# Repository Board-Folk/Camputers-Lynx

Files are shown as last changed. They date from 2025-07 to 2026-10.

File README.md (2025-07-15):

# Camputers Lynx 48/96/128/192

Repository for the 2023 Board Folk Recreation of the main boards of the Camputers Lynx 48/96K and 128K (192K) computers.

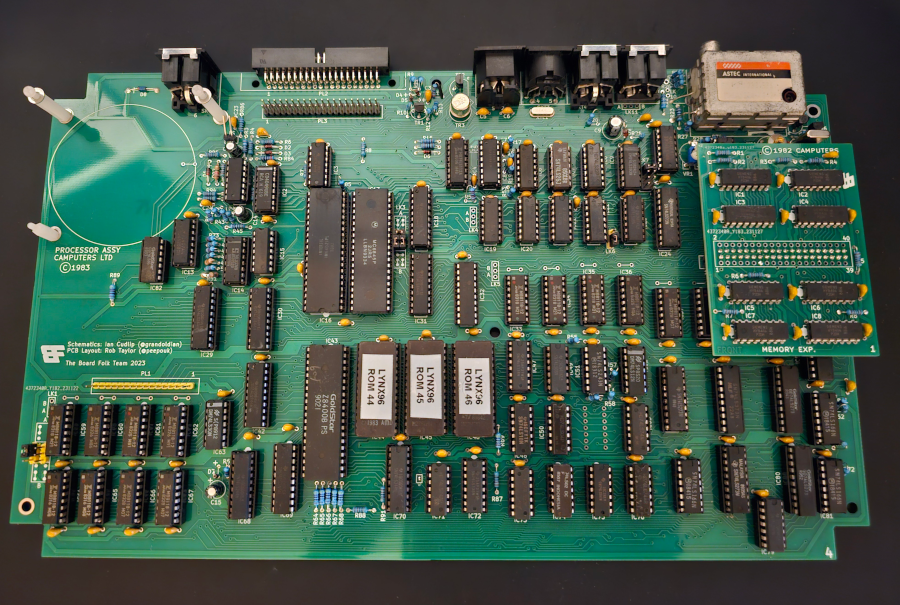
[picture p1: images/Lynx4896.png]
Built 48/96K board in Green


** Work in progress **

The original 48/96K system can be found in the Lynx 96 folder. The system needs the 16K RAM expansion board to operate (see Expansions folder). This was originally supplied as a 48K system (16K+16K+16K) then retrofitted after market by the manufacturer to be a 96K system (64K+16K+16K). It's the same board.

The second system that started production, the 128, is in the Lynx 128 folder. This system in production had presets to 128K, though could have 192K fitted. The 128K preset board (untested) can be found here. There's also a tested board without presets which can be jumpered to use 192K and can be found in the archive subfolder off here. 

Though the board without presets and appropriate jumpers set has been tested, and seems to work fine, any attempts for it to use 192K failed. It's perceived that it might need a different set of ROMs that we don't have. We're not experts and will have to defer to the Lynx community on that. See the info folder in there for jumper settings.

Be wary, the two systems aren't 100% compatible. The most compatible system is a Lynx 48 for games. The Lynx 128, compatibility was much reduced, though CP/M (untested) was an option with ROM replacements and a disc interface.

Kicad files, Gerbers and iBOMs in their respective folders for now. More information, pictures, etc may follow in time.

Keyboard boards can be found off the Expansions sub-folder in Lynx 96.

To note, we had terrible problems with RCA brand CD4538BE building these, please avoid.

## Credit

PCB layouts by Rob Taylor @peepouk. Schematics recreated by Ian Cudlip @grandoldian.

## Thanks

  * The rest of the Board Folk Team

## Legal

As the product of this project is a replica of a proprietary product, the the author makes no claim of copyright to the schematics nor PCB layouts and releases these into the public domain, solely for the purposes of study and historical preservation.

You are free to produce PCBs based on this project's designs at your own risk and without limitation, for your own use or for sale and/or repair at a reasonable price. Attribution is appreciated. The authors are not obliged to provide support of any kind. 

Under no circumstances will the authors be held responsible or liable in any way for losses, damages or costs resulting from the use of the information and/or resources of this project. 

The resources are provided "as-is" without warranty of any kind, either expressed or implied, including, but not limited to, the implied warranties of merchantability and fitness for a particular purpose.

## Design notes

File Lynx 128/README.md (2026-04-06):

# Camputers Lynx 128K

 Camputers Lynx 128K Mark 2 Issue A

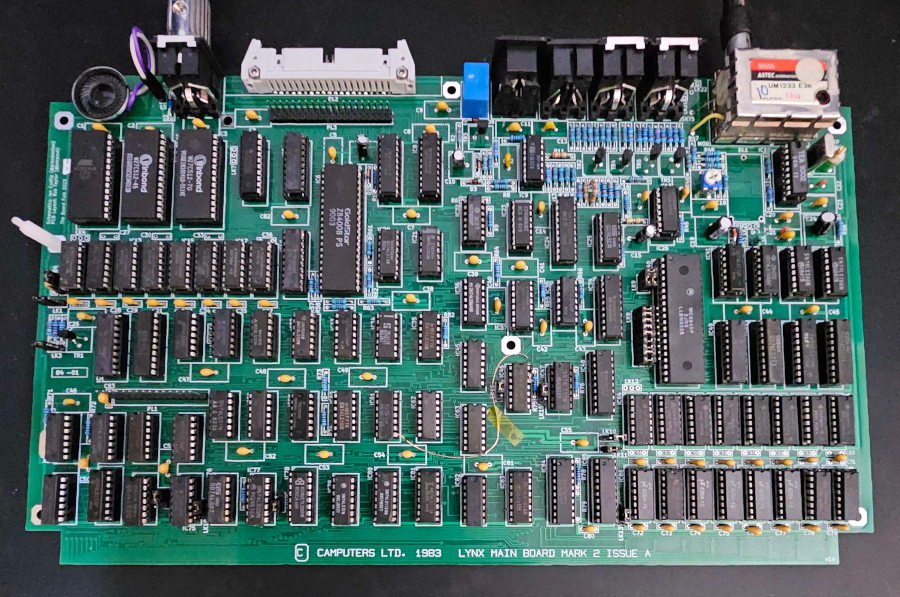
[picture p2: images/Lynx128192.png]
Built 192K board in green


The version in this folder hasn't been made. We don't see why this shouldn't work. We have tested the board in the Archive/Lynx 192 folder though, but not working to 192K capacity, see any notes in there. That version does not have the RAM configuration jumpers preset which we perceive might be beneficial to some. This still needs the single bodge wire running, will try to dig out the exact details, it's been a while. Other factory bodges (to the bottom) were to fix factory defects that aren't present on this board.

Alternatives for the relay are the Fujitsu 211A 0005-M, and the JRC-21F(4100) 5V (found on AliExpress). The OUAZ-SH-105D is *not* pin compatible. It's the same relay as found on the Acorn Electron and BBC Micro.

This is a horrible merry-go-round of a board to debug and not for the feint hearted.

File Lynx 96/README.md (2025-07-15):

# Camputers-Lynx-96K

Camputers Lynx 48/96K Issue 4

Built 48/96K board in Green

For jumper settings, see the info folder.

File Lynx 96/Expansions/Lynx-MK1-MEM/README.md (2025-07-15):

# Lynx MK1 MEM (Improved)

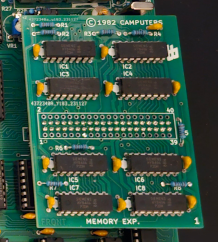
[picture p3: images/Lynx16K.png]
Built 16K expansion board in green


Lynx MK1 16K Memory Expansion

This is a replica, with modifications moving a capacitor and adding holes for straight pin socket headers.

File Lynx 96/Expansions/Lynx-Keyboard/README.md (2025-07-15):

# Lynx Keyboard

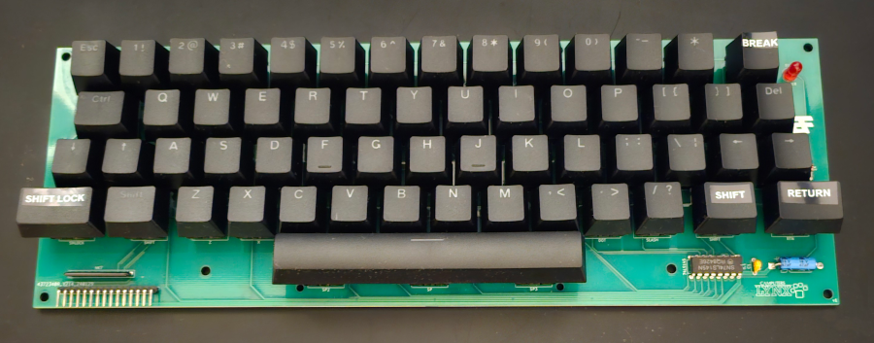
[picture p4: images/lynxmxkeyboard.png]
Built MX compatible keyboard board in green with black keycaps


Lynx MX Keyswitch Compatible Keyboard

Thanks to Graham Thornton for measurements. We've still not been able to try see if it fits an original case though.

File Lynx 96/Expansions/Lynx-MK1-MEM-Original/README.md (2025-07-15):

# Lynx MK1 MEM (Original)

Lynx MK1 16K Memory Expansion

This is an replica, please note the offset on the pin sockets. The main folder contains an updated version with straight pins.

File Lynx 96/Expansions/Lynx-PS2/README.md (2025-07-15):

# Lynx PS2

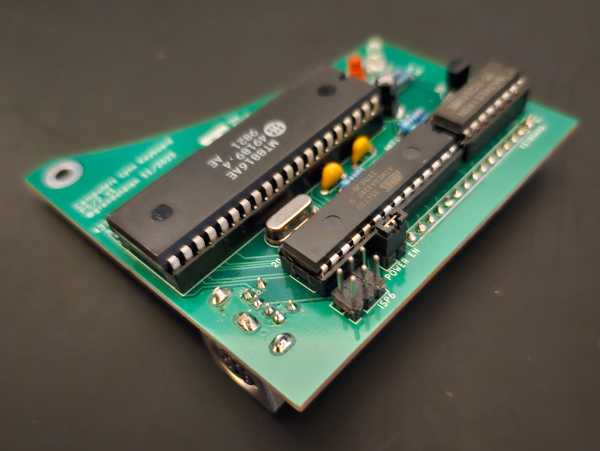
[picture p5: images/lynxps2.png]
Built PS/2 interface board in Green


ATMega328 based PS/2 Keyboard Adapter for the Camputers Lynx. Arduino code and exported binaries in the Arduino folder.

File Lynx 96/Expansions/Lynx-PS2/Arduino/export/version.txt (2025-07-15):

# Lynx PS/2 Keyboard / atmega328p
# Ian Cudlip @grandoldian 12/2023

v0

Initial version
Print Screen as NMI reset "Break"

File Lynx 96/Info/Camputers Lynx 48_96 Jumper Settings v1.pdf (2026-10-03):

LK1

# Camputers Lynx 48/96K Mark I Jumper Settings @grandoldian 10/2026 v1.2 (Board Folk v1n Board)

1

3

2

B

A

System RAM Bank 1 Pin 1
Voltage Selection
4116 RAM
1-2 -5V

3

2

1

4164/8118
RAM
NF

LK3

B

Video RAM (Bank 2)
Mode Selection

1

3

2

4

6

5

Default
1-4
2-3
5-6

LK2
A

B

System RAM Bank 1 Pin 8 and 9 Mode Selection

1

3

2

4

6

5

4164 RAM
1-2 5V
4-5 A7

1

3

2

4

6

5

4116 RAM
2-3 12V
5-6 5V

1

3

2

4

6

5

8118 RAM
1-2 5V
4-6 NF

1

3

2

4

6

5

Extended
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
VCLK Selection
(Not Fitted / Preconfigured) 12MHz
(Default)

1

2

3

24Mhz

LK5

3

1

2

B

A

Video RAM Bank 2 Pin 9
Mode Selection
4116 RAM
2-3 +5V

1

2

3

4164
RAM
1-2 A7

LK6

3

1

2

B

A

/VCASII Select
Use 1-2 (South)
Unknown
(?)

1

2

3

Default
(?)

LK7 Baud Rate Select
TBD

1

5

3

2

6

4

1-2 ? Baud
3-4 ? Baud
5-6 ? Baud
7-8 ? Baud

7 8

LK8 Video RAM Bank 2 Pin 1 Voltage Selection

1 2

4116
1-2 -5V

1 2

4164/8118
NF

LK9

1

3

2

B

A

Video RAM Bank 2 Pin 8
Voltage Selection
4116 RAM
1-2 12V

3

2

1

4164/8118
RAM
2-3 5V

LK10

1

2

Modulator Additional Ground (Not Fitted / Preconfigured On) Ground

LK11 RGB Voltage
(Not Fitted / Preconfigured RoW)

3 2

Ground
RoW (Default)

3 2

+12V
France

1

1

1

2

3

8118
RAM
NF

Notes:

Onboard, Bank 1 is System RAM, Bank 2 is Video RAM. PL4 expansion is Video RAM, which is required.

A 48K system is 16K System RAM, 16K Video RAM on-board, with a 16K Video RAM expansion card at PL4 A 96K system is 64K System RAM, 16K Video RAM on-board, with a 16K Video RAM expansion card at PL4

Both of these use the Default LK3 configuration, Extended needs further documentation.

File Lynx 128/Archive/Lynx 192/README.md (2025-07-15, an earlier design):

# Camputers Lynx 192K

Camputers Lynx 128K Mark 2 Issue A without the RAM jumpers preset. It can be populated with 3 sets of 4164 RAM.

We've tested this board, but not to 192K capacity. We think it might need a different ROM. This does not set the RAM configuration jumpers as the manufacturered 128K board did. This still needs the single bodge wire running. Other factory bodges were to fix factory defects that aren't present on this board.

For jumper settings, see the info folder.

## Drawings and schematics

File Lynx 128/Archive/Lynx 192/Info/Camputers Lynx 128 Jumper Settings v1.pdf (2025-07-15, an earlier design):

LK4

# Camputers Lynx Mark 2 Jumper Settings

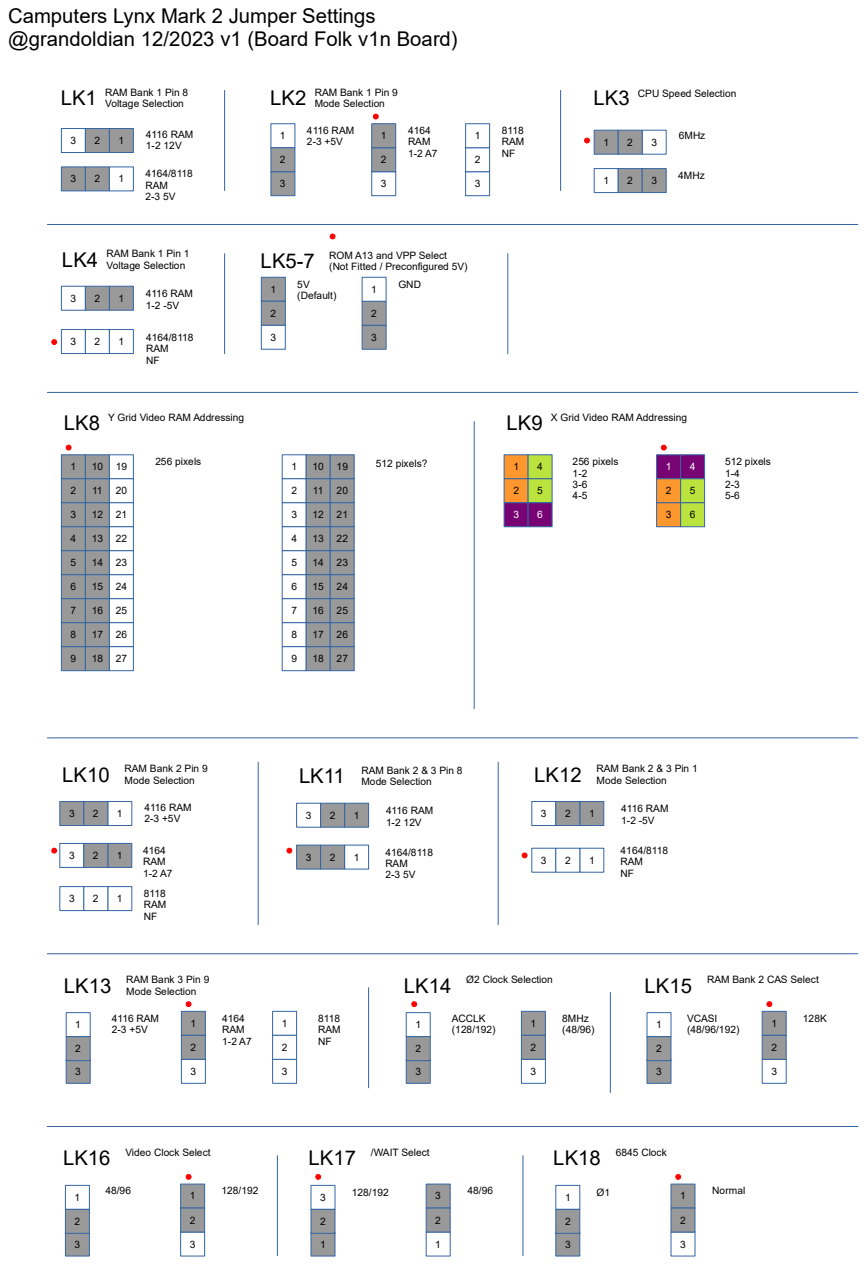
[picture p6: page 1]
4116 RAM 1-2 -5V; 4164/8118 RAM NF; Mode Selection; 4116 RAM 2-3 +5V; 4164 RAM 1-2 A7; 8118 RAM NF; 4116 RAM 1-2 12V; 4164/8118 RAM 2-3 5V; Voltage Selection; 6MHz; 4MHz; ROM A13 and VPP Select (Not Fitted / Preconfigured 5V); 5V (Default); GND; 256 pixels; 512 pixels?; 256 pixels 1-2 3-6 4-5; 512 pixels 1-4 2-3 5-6; Ø2 Clock Selection; ACCLK (128/192); 8MHz (48/96) 1; VCASI (48/96/192); /WAIT Select; 6845 Clock; Normal 1

@grandoldian 12/2023 v1 (Board Folk v1n Board)

RAM Bank 1 Pin 8

RAM Bank 1 Pin 9

CPU Speed Selection

RAM Bank 1 Pin 1
Voltage Selection

LK8 Y Grid Video RAM Addressing

LK9 X Grid Video RAM Addressing

RAM Bank 2 Pin 9

RAM Bank 2 & 3 Pin 8

RAM Bank 2 & 3 Pin 1

RAM Bank 3 Pin 9

RAM Bank 2 CAS Select

Video Clock Select

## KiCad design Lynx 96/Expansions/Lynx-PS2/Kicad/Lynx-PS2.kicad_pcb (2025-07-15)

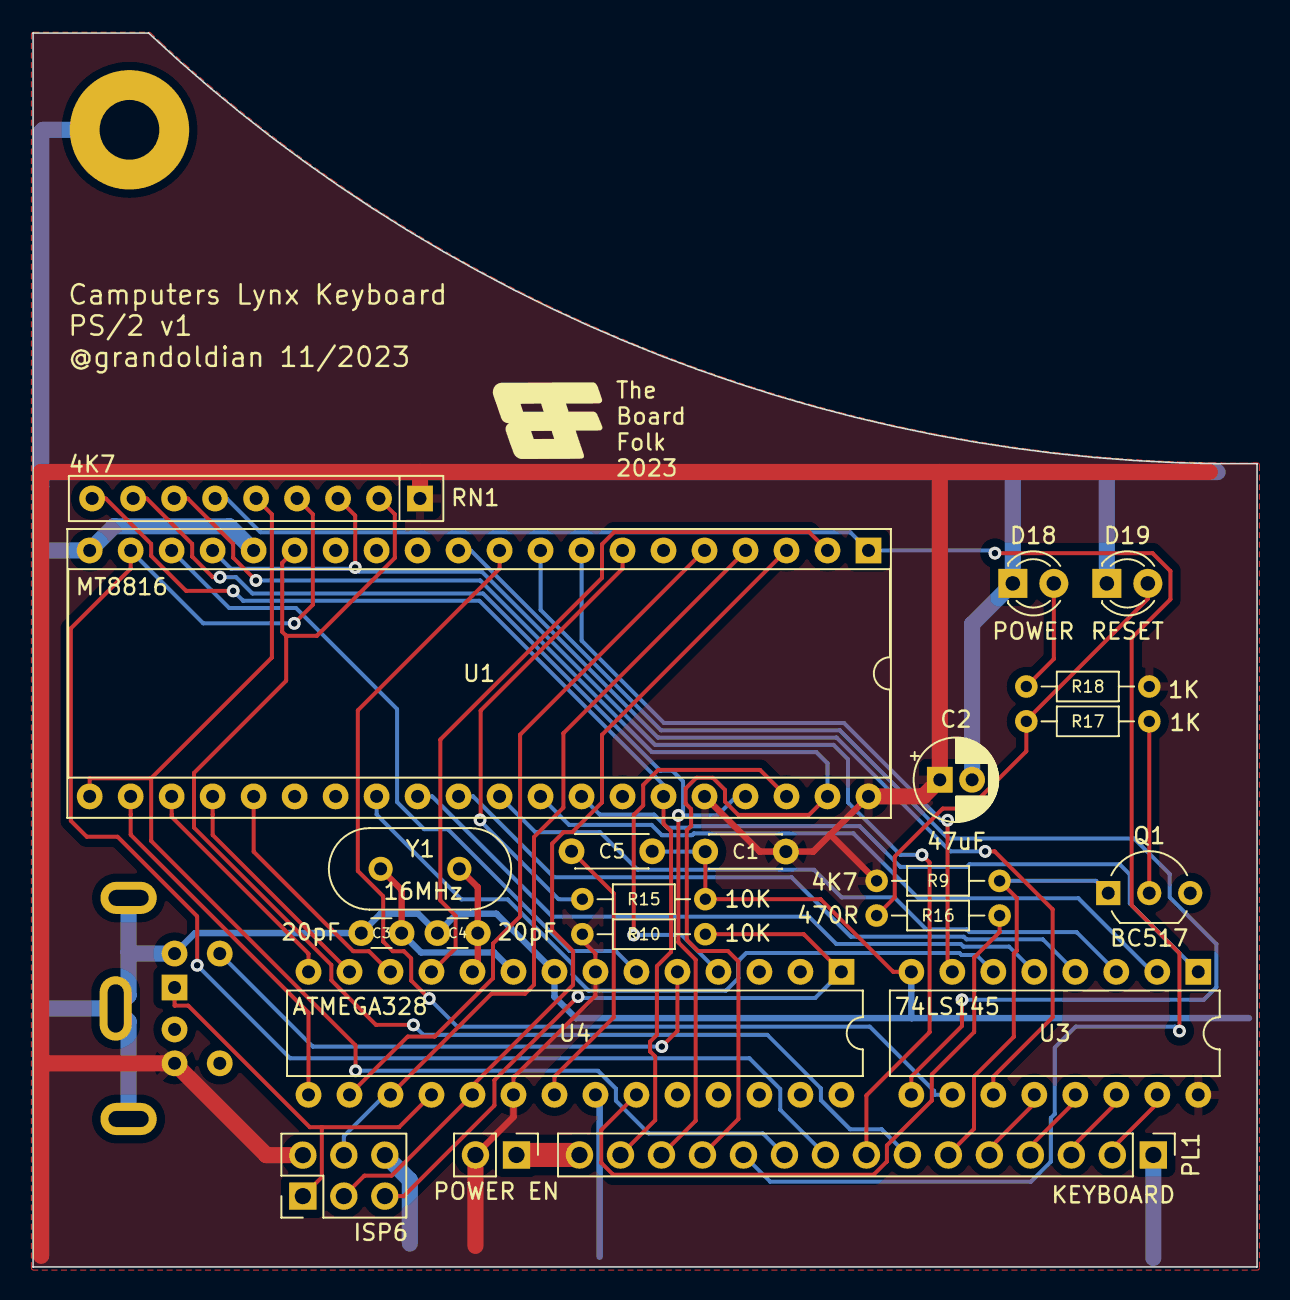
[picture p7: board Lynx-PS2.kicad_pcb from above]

Board: 2 copper layers, 75.8 x 76.5 mm, 25 parts (1 on the bottom side), 47 nets.

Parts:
C1: 47nF; C_Disc_D4.3mm_W1.9mm_P5.00mm
C2: 47uF; CP_Radial_D5.0mm_P2.00mm
C3, C4: 20pF; C_Disc_D3.0mm_W1.6mm_P2.50mm
C5: 100nF; C_Disc_D4.3mm_W1.9mm_P5.00mm
D18: POWER; LED_D3.0mm
D19: RESET; LED_D3.0mm
G1: Board Folk Logo; BF8
H1: Hole; MountingHole_3.7mm_Pad
J1: POWER EN; PinHeader_1x02_P2.54mm_Vertical
J3: PS/2; Connector_Mini-DIN_Female_6Pin_2rows
J800: ISP6; PinHeader_2x03_P2.54mm_Vertical
PL1: KEYBOARD; PinHeader_1x15_P2.54mm_Vertical
Q1: BC517; TO-92_Inline_Wide
R9: 4K7; R_Axial_DIN0204_L3.6mm_D1.6mm_P7.62mm_Horizontal
R10, R15: 10K; R_Axial_DIN0204_L3.6mm_D1.6mm_P7.62mm_Horizontal
R16: 470R; R_Axial_DIN0204_L3.6mm_D1.6mm_P7.62mm_Horizontal
R17, R18: 1K; R_Axial_DIN0204_L3.6mm_D1.6mm_P7.62mm_Horizontal
RN1: 4K7; R_Array_SIP9
U1: MT8816; DIP-40_W15.24mm_Socket
U3: 74LS145; DIP-16_W7.62mm
U4: ATMEGA328; DIP-28_W7.62mm
Y1: 16MHz; Crystal_HC49-U_Vertical

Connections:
!RST: PL1.6, Q1.1 (C), R9.1
+5V: C1.2, C2.1, J1.2, J3.4, J800.2, R9.2, R10.1, R18.2, RN1.1 (common), U1.36, U1.40, U3.16 (VCC), U4.7 (VCC), U4.20 (AVCC)
/KBA0: PL1.2, U3.15 (A)
/KBA1: PL1.3, U3.14 (B)
/KBA2: PL1.4, U3.13 (C)
/KBA3: PL1.5, U3.12 (D)
ADMISO: J3.1, J800.1, U4.18 (PB4)
ADMOSI: J800.4, U1.4, U4.17 (PB3)
ADRESET: J800.5, R10.2, U4.1 (PC6)
ADSCK: J800.3, U1.3, U4.19 (PB5)
AX0: U1.5, U4.16 (PB2)
AX1: U1.22, U4.15 (PB1)
AX2: U1.23, U4.14 (PB0)
AY0: U1.24, U4.13 (PD7)
AY1: U1.25, U4.12 (PD6)
AY2: U1.2, U4.11 (PD5)
BREAK: R16.2, U4.23 (PC0)
COL0: U1.33, U3.1 (~Q0)
COL1: U1.32, U3.2 (~Q1)
COL2: U1.31, U3.3 (~Q2)
COL3: U1.30, U3.4 (~Q3)
COL4: U1.29, U3.5 (~Q4)
COL5: U1.28, U3.6 (~Q5)
COL6: U1.8, U3.7 (~Q6)
COL7: U1.9, U3.9 (~Q7)
COL8: U1.10, U3.10 (~Q8)
COL9: U1.11, U3.11 (~Q9)
FLOAT: R15.1, U1.7
GND: C1.1, C2.2, C3.2, C4.2, C5.2, D18.1 (K), D19.1 (K), H1.1, J3.3, J3.7, J800.6, PL1.1, Q1.3 (E), R15.2, U1.16, U1.20, U3.8 (GND), U4.8 (GND), U4.22 (GND)
MTDATA: U1.38, U4.4 (PD2)
MTSTROBE: U1.18, U4.6 (PD4)
unnamed: D18.2 (A), R18.1
unnamed: D19.2 (A), R16.1, R17.2
unnamed: J1.1, PL1.15
unnamed: Q1.2 (B), R17.1
unnamed: C5.1, U4.21 (AREF)
unnamed: C3.1, U4.9 (PB6), Y1.1
unnamed: C4.1, U4.10 (PB7), Y1.2
PS2-CLK: J3.5, U4.5 (PD3)
ROW0: PL1.14, RN1.9 (R8), U1.35
ROW1: PL1.13, RN1.8 (R7), U1.37
ROW2: PL1.12, RN1.7 (R6), U1.39
ROW3: PL1.11, RN1.6 (R5), U1.1
ROW4: PL1.10, RN1.5 (R4), U1.21
ROW5: PL1.9, RN1.4 (R3), U1.19
ROW6: PL1.8, RN1.3 (R2), U1.17
ROW7: PL1.7, RN1.2 (R1), U1.15

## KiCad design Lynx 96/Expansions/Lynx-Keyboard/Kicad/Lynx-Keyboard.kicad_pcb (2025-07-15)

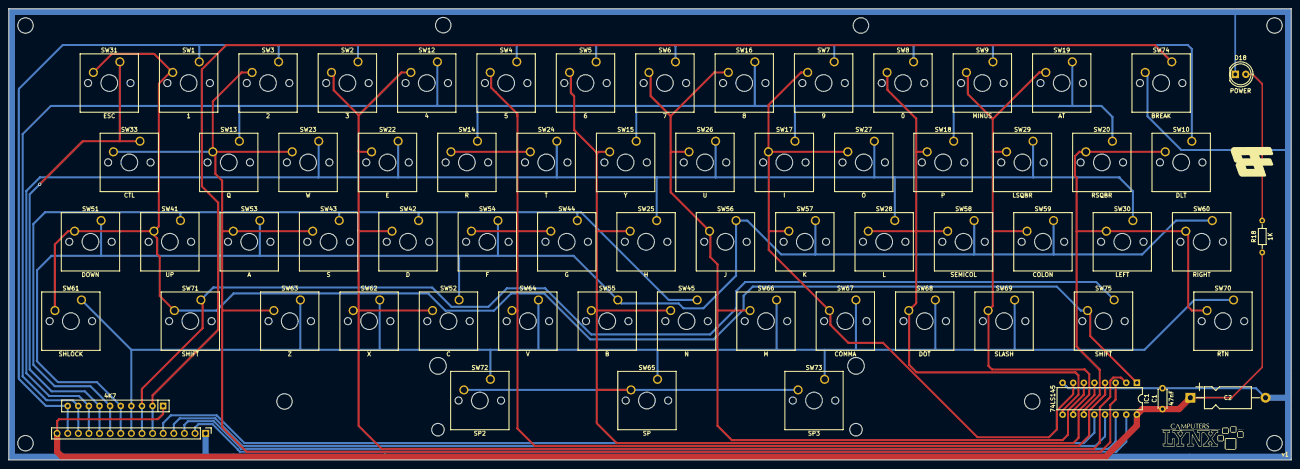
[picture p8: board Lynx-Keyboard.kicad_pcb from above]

Board: 2 copper layers, 307.0 x 108.0 mm, 78 parts (1 on the bottom side), 26 nets.

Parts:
C1: 47nF; C_Disc_D4.3mm_W1.9mm_P5.00mm
C2: 47uF; CP_Axial_L11.0mm_D5.0mm_P18.00mm_Horizontal
D18: POWER; LED_D5.0mm
G1: Board Folk Logo; BF12
G2: Camputer Lynx Logo; CLLogo
G3: Board Folk QR; bf_qr14
H1, H2, H3, H4, H5, H6, H7, H8: Hole; MountingHole_3.7mm
IC1: 74LS145; DIP-16_W7.62mm
PL1: KEYBOARD; PinHeader_1x15_P2.54mm_Vertical
R18: 1K; R_Axial_DIN0204_L3.6mm_D1.6mm_P7.62mm_Horizontal
RN1: 4K7; R_Array_SIP10
SW1: 1; SW_Cherry_MX_1.00u_PCB
SW2: 3; SW_Cherry_MX_1.00u_PCB
SW3: 2; SW_Cherry_MX_1.00u_PCB
SW4: 5; SW_Cherry_MX_1.00u_PCB
SW5: 6; SW_Cherry_MX_1.00u_PCB
SW6: 7; SW_Cherry_MX_1.00u_PCB
SW7: 9; SW_Cherry_MX_1.00u_PCB
SW8: 0; SW_Cherry_MX_1.00u_PCB
SW9: MINUS; SW_Cherry_MX_1.00u_PCB
SW10: DLT; SW_Cherry_MX_1.00u_PCB
SW12: 4; SW_Cherry_MX_1.00u_PCB
SW13: Q; SW_Cherry_MX_1.00u_PCB
SW14: R; SW_Cherry_MX_1.00u_PCB
SW15: Y; SW_Cherry_MX_1.00u_PCB
SW16: 8; SW_Cherry_MX_1.00u_PCB
SW17: I; SW_Cherry_MX_1.00u_PCB
SW18: P; SW_Cherry_MX_1.00u_PCB
SW19: AT; SW_Cherry_MX_1.00u_PCB
SW20: RSQBR; SW_Cherry_MX_1.00u_PCB
SW22: E; SW_Cherry_MX_1.00u_PCB
SW23: W; SW_Cherry_MX_1.00u_PCB
SW24: T; SW_Cherry_MX_1.00u_PCB
SW25: H; SW_Cherry_MX_1.00u_PCB
SW26: U; SW_Cherry_MX_1.00u_PCB
SW27: O; SW_Cherry_MX_1.00u_PCB
SW28: L; SW_Cherry_MX_1.00u_PCB
SW29: LSQBR; SW_Cherry_MX_1.00u_PCB
SW30: LEFT; SW_Cherry_MX_1.00u_PCB
SW31: ESC; SW_Cherry_MX_1.00u_PCB
SW33: CTL; SW_Cherry_MX_1.50u_PCB
SW41: UP; SW_Cherry_MX_1.00u_PCB
SW42: D; SW_Cherry_MX_1.00u_PCB
SW43: S; SW_Cherry_MX_1.00u_PCB
SW44: G; SW_Cherry_MX_1.00u_PCB
SW45: N; SW_Cherry_MX_1.00u_PCB
SW51: DOWN; SW_Cherry_MX_1.00u_PCB
SW52: C; SW_Cherry_MX_1.00u_PCB
SW53: A; SW_Cherry_MX_1.00u_PCB
SW54: F; SW_Cherry_MX_1.00u_PCB
SW55: B; SW_Cherry_MX_1.00u_PCB
SW56: J; SW_Cherry_MX_1.00u_PCB
SW57: K; SW_Cherry_MX_1.00u_PCB
SW58: SEMICOL; SW_Cherry_MX_1.00u_PCB
SW59: COLON; SW_Cherry_MX_1.00u_PCB
SW60: RIGHT; SW_Cherry_MX_1.00u_PCB
SW61: SHLOCK; SW_Cherry_MX_1.50u_PCB
SW62: X; SW_Cherry_MX_1.00u_PCB
SW63: Z; SW_Cherry_MX_1.00u_PCB
SW64: V; SW_Cherry_MX_1.00u_PCB
SW65: SP; SW_Cherry_MX_1.00u_PCB
SW66: M; SW_Cherry_MX_1.00u_PCB
SW67: COMMA; SW_Cherry_MX_1.00u_PCB
SW68: DOT; SW_Cherry_MX_1.00u_PCB
SW69: SLASH; SW_Cherry_MX_1.00u_PCB
SW70: RTN; SW_Cherry_MX_1.50u_PCB
SW71, SW75: SHIFT; SW_Cherry_MX_1.50u_PCB
SW72: SP2; SW_Cherry_MX_1.00u_PCB
SW73: SP3; SW_Cherry_MX_1.00u_PCB
SW74: BREAK; SW_Cherry_MX_1.50u_PCB

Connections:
!RST: PL1.6, RN1.2 (R1), SW74.1 (A)
+5V: C1.2, C2.1, IC1.16 (VCC), PL1.15, R18.2, RN1.1 (common)
/KBA0: IC1.15 (A), PL1.2
/KBA1: IC1.14 (B), PL1.3
/KBA2: IC1.13 (C), PL1.4
/KBA3: IC1.12 (D), PL1.5
COL0: IC1.1 (~Q0), SW1.2 (B), SW31.2 (B), SW41.2 (B), SW51.2 (B), SW61.2 (B), SW71.2 (B), SW75.2 (B)
COL1: IC1.2 (~Q1), SW2.2 (B), SW12.2 (B), SW22.2 (B), SW42.2 (B), SW52.2 (B), SW62.2 (B)
COL2: IC1.3 (~Q2), SW3.2 (B), SW13.2 (B), SW23.2 (B), SW33.2 (B), SW43.2 (B), SW53.2 (B), SW63.2 (B)
COL3: IC1.4 (~Q3), SW4.2 (B), SW14.2 (B), SW24.2 (B), SW44.2 (B), SW54.2 (B), SW64.2 (B)
COL4: IC1.5 (~Q4), SW5.2 (B), SW15.2 (B), SW25.2 (B), SW45.2 (B), SW55.2 (B), SW65.2 (B), SW72.2 (B), SW73.2 (B)
COL5: IC1.6 (~Q5), SW6.2 (B), SW16.2 (B), SW26.2 (B), SW56.2 (B), SW66.2 (B)
COL6: IC1.7 (~Q6), SW7.2 (B), SW17.2 (B), SW27.2 (B), SW57.2 (B), SW67.2 (B)
COL7: IC1.9 (~Q7), SW8.2 (B), SW18.2 (B), SW28.2 (B), SW58.2 (B), SW68.2 (B)
COL8: IC1.10 (~Q8), SW9.2 (B), SW19.2 (B), SW29.2 (B), SW59.2 (B), SW69.2 (B)
COL9: IC1.11 (~Q9), SW10.2 (B), SW20.2 (B), SW30.2 (B), SW60.2 (B), SW70.2 (B)
GND: C1.1, C2.2, D18.1 (K), IC1.8 (GND), PL1.1, SW74.2 (B)
unnamed: D18.2 (A), R18.1
ROW0: PL1.14, RN1.10 (R9), SW1.1 (A), SW2.1 (A), SW3.1 (A), SW4.1 (A), SW5.1 (A), SW6.1 (A), SW7.1 (A), SW8.1 (A), SW9.1 (A), SW10.1 (A)
ROW1: PL1.13, RN1.9 (R8), SW12.1 (A), SW13.1 (A), SW14.1 (A), SW15.1 (A), SW16.1 (A), SW17.1 (A), SW18.1 (A), SW19.1 (A), SW20.1 (A)
ROW2: PL1.12, RN1.8 (R7), SW22.1 (A), SW23.1 (A), SW24.1 (A), SW25.1 (A), SW26.1 (A), SW27.1 (A), SW28.1 (A), SW29.1 (A), SW30.1 (A)
ROW3: PL1.11, RN1.7 (R6), SW31.1 (A), SW33.1 (A)
ROW4: PL1.10, RN1.6 (R5), SW41.1 (A), SW42.1 (A), SW43.1 (A), SW44.1 (A), SW45.1 (A)
ROW5: PL1.9, RN1.5 (R4), SW51.1 (A), SW52.1 (A), SW53.1 (A), SW54.1 (A), SW55.1 (A), SW56.1 (A), SW57.1 (A), SW58.1 (A), SW59.1 (A), SW60.1 (A)
ROW6: PL1.8, RN1.4 (R3), SW61.1 (A), SW62.1 (A), SW63.1 (A), SW64.1 (A), SW65.1 (A), SW66.1 (A), SW67.1 (A), SW68.1 (A), SW69.1 (A), SW70.1 (A), SW72.1 (A), SW73.1 (A)
ROW7: PL1.7, RN1.3 (R2), SW71.1 (A), SW75.1 (A)

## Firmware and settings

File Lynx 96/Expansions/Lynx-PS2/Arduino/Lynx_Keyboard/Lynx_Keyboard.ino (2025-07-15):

/*
  Lynxkeyboard - Camputers Lynx Keyboard Library
  Adapted by Ian Cudlip
  v0 08/11/2023
  
  Based on C64keyboard - Commodore Keyboard library by Hartland PC LLC
  Copyright (c) 2022 Hartland PC LLC
  Written by Robert VanHazinga

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
  You should have received a copy of the GNU Lesser General Public
  License along with this library; if not, write to the Free Software
  Foundation, Inc., 51 Franklin St, Fifth Floor, Boston, MA  02110-1301  USA
*/

#include <PS2KeyAdvanced.h>
#include "Lynxkeyboard.h"

PS2KeyAdvanced keyboard;
Lynxkeyboard ckey;
static volatile uint8_t  currkeymap = 1, flags ;
static const LynxKeymap_t *keymap = NULL;
static volatile bool lshift=false, rshift=false, capslock=false, Lynxbreak=false;

void setup() {
  // Configure the keyboard library
  keyboard.begin( DATA_PIN, IRQ_PIN );
  keyboard.setNoRepeat (1);
  keyboard.setNoBreak (0);
  ckey.begin();
 if (debug) {Serial.begin( 9600 );
 Serial.println("Startup..");
 }
}

void loop() {
 if ( keyboard.available() )
 {
   Lynxkey(keyboard.read());  
 }
}

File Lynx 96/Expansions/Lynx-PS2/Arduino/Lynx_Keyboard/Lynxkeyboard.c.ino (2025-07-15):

/*
  Lynxkeyboard - Camputers Lynx Keyboard Library
  Adapted by Ian Cudlip

  Based on C64keyboard - Commodore Keyboard library by Hartland PC LLC
  Copyright (c) 2022 Hartland PC LLC
  Written by Robert VanHazinga

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
  You should have received a copy of the GNU Lesser General Public
  License along with this library; if not, write to the Free Software
  Foundation, Inc., 51 Franklin St, Fifth Floor, Boston, MA  02110-1301  USA
*/
#include "Lynxkeyboard.h"

void resetMT88(void) {
  digitalWrite(ANALOG_SW_DATA , LOW);
  digitalWrite(ANALOG_SW_RESET, HIGH);
  digitalWrite( ANALOG_SW_STROBE, HIGH);
  digitalWrite(ANALOG_SW_RESET, LOW);
  digitalWrite( ANALOG_SW_STROBE, LOW);
  digitalWrite(ANALOG_SW_DATA , HIGH);
  keyboard.setLock (PS2_LOCK_SCROLL && 0);
  capslock = false;
  lshift = false;
  rshift = false;
  currkeymap = 1;
  }

void setswitch(uint16_t c){
  int bitr;
  bool state;
  
  // Fix logic table hole in MT8812/16 and things
  // AX3 line control. There must be a more logical way of working this out.
  if (!MT8808) {
    // any required modifiers here, hopefully none.
    if (c>63) {
      digitalWrite(ANALOG_SW_AX3, LOW);
    } else {
      digitalWrite(ANALOG_SW_AX3, HIGH);
    }
  }

  if (debug){
    Serial.println(c);
  }
  
  if (c < 160) {
    for ( int currentPin = ANALOG_SW_ARRAY_START; currentPin <= ANALOG_SW_ARRAY_END; ++currentPin) {
      bitr = (currentPin - ANALOG_SW_ARRAY_START);
      state =  bitRead(c, bitr);
      digitalWrite(currentPin, state);
    }
    digitalWrite( ANALOG_SW_STROBE, HIGH);
    digitalWrite( ANALOG_SW_STROBE, LOW);
  }
  if (!MT8808){digitalWrite(ANALOG_SW_AX3, LOW);}

}

void setfswitch(uint16_t c){
  int bitr;
  bool state;
  
   digitalWrite(ANALOG_SW_AX3, HIGH);

  if (c < 160) {
    for ( int currentPin = ANALOG_SW_ARRAY_START; currentPin <= ANALOG_SW_ARRAY_END; ++currentPin) {
      bitr = (currentPin - ANALOG_SW_ARRAY_START);
      state =  bitRead(c, bitr);
      digitalWrite(currentPin, state);
    }
    digitalWrite( ANALOG_SW_STROBE, HIGH);
    digitalWrite( ANALOG_SW_STROBE, LOW);
  }
  
  digitalWrite(ANALOG_SW_AX3, LOW);

}

void debugkey (uint16_t c,uint8_t flags,uint8_t kc){
    Serial.print ("Lynx Keycode: ");
    Serial.print (c);
    Serial.print ("  (ASCII Code: ");
    Serial.print (kc);
    Serial.print (" Hex: ");
    Serial.print (kc, HEX);
    Serial.print (")  Flags: ");
      for (int i = 7; i >= 0; i--)
    {
        bool b = bitRead(flags, i);
        Serial.print(b);
    }
    Serial.println();
  }
    
void Lynxkey(uint16_t k) {
   flags = k >> 8;
   uint8_t kc= k & 0xFF;
   uint16_t c = 0;

  if (currkeymap == 2) {
    if (bitRead(flags, 6)) {
      c = pgm_read_word(keymap->shift_2 + kc);
    }
    else {
      c = pgm_read_word(keymap->noshift_2 + kc);
    }
  }

   if (currkeymap == 1) {
    if (bitRead(flags, 6)) {
      c = pgm_read_word(keymap->shift_1 + kc);
    }
    else {
      c = pgm_read_word(keymap->noshift_1 + kc);
    }
  }
  
//  debug output
    if (debug){debugkey(c,flags,kc);}

// Ignore extended codes 
    if (kc == 250){
      if (debug){
        Serial.println("Ignore");
      }
      c=IGNORE_KEYCODE;
      }

// Lynx Break Key
    if (kc == LynxBREAK) {
      if (bitRead(flags, 7)) {
        Lynxbreak=false;
        digitalWrite(LynxBREAK_PIN, LOW);
        if (debug) {
          Serial.println("Break Off");
        } 
      } else {     
        Lynxbreak=true;
        digitalWrite(LynxBREAK_PIN, HIGH);
        if (debug) {
          Serial.println("Break On");
        } 
      }
      c=IGNORE_KEYCODE;
    }
    
// MT reset function    
    if (kc == MT_RESET) {
    resetMT88();  
    c=IGNORE_KEYCODE;
   }   
    
// Capslock function 

    if (kc == CAPSLOCK_KEY) {
      capslock = !capslock;
      if (debug) {
        if (capslock)  {
          Serial.println("Caps Lock On");
        } else {
          Serial.println("Caps Lock Off");
        }
      }
      
      digitalWrite (ANALOG_SW_DATA, HIGH);
      setswitch(6);
      delay(100);
      digitalWrite (ANALOG_SW_DATA, LOW);
      setswitch(6);
      c = IGNORE_KEYCODE; 
      }


// Keymap Handling
    if (kc == KEY_MAP_1 && !bitRead(flags,7)){
      currkeymap = 1;
      keyboard.setLock (PS2_LOCK_SCROLL && 0);
      }

    if (kc == KEY_MAP_2 && !bitRead(flags,7)){
      currkeymap = 2;
      keyboard.setLock (PS2_LOCK_SCROLL && 1);
      }
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

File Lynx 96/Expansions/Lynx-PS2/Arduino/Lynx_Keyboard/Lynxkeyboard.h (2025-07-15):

/*
  Lynxkeyboard - Camputers Lynx Keyboard Library
  Adapted by Ian Cudlip

  Based on C64keyboard - Commodore Keyboard library by Hartland PC LLC
  Copyright (c) 2022 Hartland PC LLC
  Written by Robert VanHazinga

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
  You should have received a copy of the GNU Lesser General Public
  License along with this library; if not, write to the Free Software
  Foundation, Inc., 51 Franklin St, Fifth Floor, Boston, MA  02110-1301  USA
*/

#ifndef Lynxkeyboard_h
#define Lynxkeyboard_h

#if defined(ARDUINO) && ARDUINO >= 100
#include "Arduino.h"
#else
#include "WProgram.h"
#endif
#define Lynx_KEYMAP_SIZE 	   152 // Size of each array in the key maps

#include "keymapping.h"

#define debug   false    // Set true for serial monitor of Lynx keycodes and PS/2 keycodes

#define MT8808  false    // This has to be set to false now as we use more lines than the MT8808 provides

//PS2 communication pins
#define DATA_PIN				12 // Data pin for PS2 keyboard
#define IRQ_PIN					3  // Interrupt pin for PS2 keyboard

//Scan code value to enable a key map. Default is key map 1.
#define KEY_MAP_1				0x6B // F11?
#define KEY_MAP_2				0x6C // F12?

//Key map value to ignore key press
#define IGNORE_KEYCODE			0x154 //(DEC 340) (Must be > 128)

// Key map value to reset the MT88xx chip
#define MT_RESET        0x6C // (DEC 108) F12 activates MT88XX reset

//MT88xx control pins
#define ANALOG_SW_DATA      2 // Sets selected cross switch on/off (Old 13)
#define ANALOG_SW_STROBE    4 // Strobe timing pulse
#define ANALOG_SW_RESET     13 // Reset all MT88XX cross switches to off (Old 2)
#define ANALOG_SW_ARRAY_START 5 // First pin of 6 bit switch addressing. AY2-0 & AX2-0
#define ANALOG_SW_ARRAY_END   10 // Last pin of 6 bit switch addressing. AY2-0 & AX2-0
#define ANALOG_SW_AX3     11 // Pin that controls AX3 (MT8812 & MT8816) 

//Lynx Break Key
#define LynxBREAK_PIN     A0

// Key map value for capslock
#define CAPSLOCK_KEY    0x03 // CapsLock key 

#define LynxLSHFT  71
#define LynxRSHFT  71

#define LynxBREAK  4

class Lynxkeyboard {
  public:
    Lynxkeyboard();
    
    static void begin(const LynxKeymap_t &map = LynxKeymap_main);
};
#endif
